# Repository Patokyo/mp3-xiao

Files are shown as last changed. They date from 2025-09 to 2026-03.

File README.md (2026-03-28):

# MP3 Xiao

A portable DIY MP3 player built using the Seeed Studio XIAO ESP32-S3

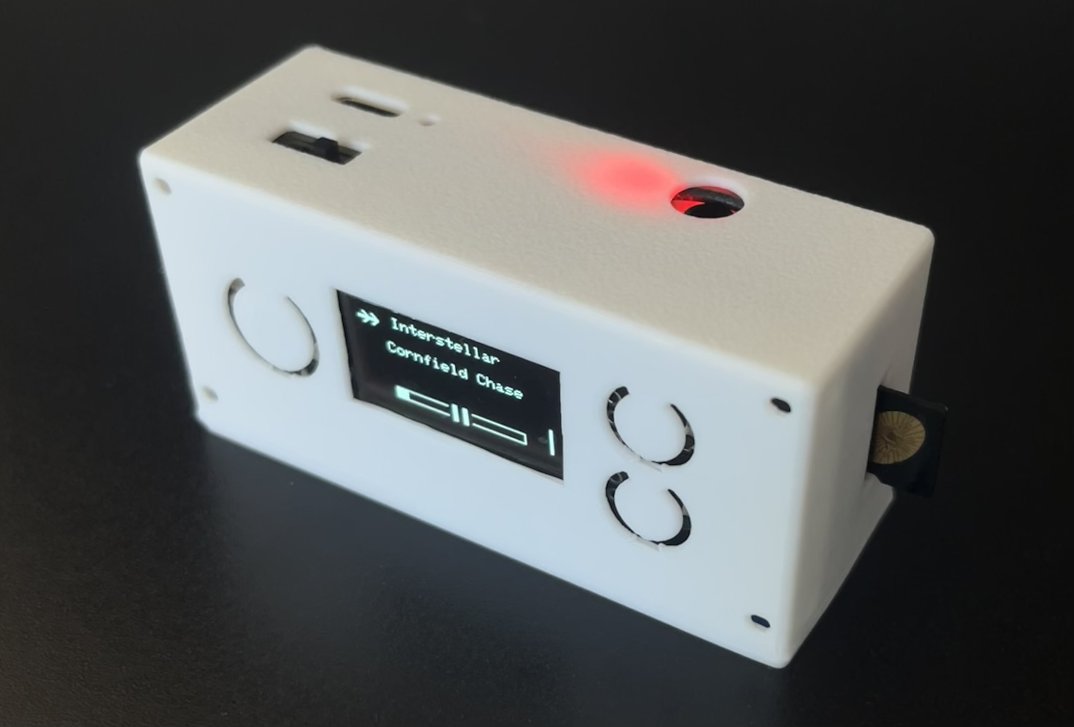
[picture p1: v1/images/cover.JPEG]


## Overview

MP3 Xiao is a compact, battery-powered music player designed from scratch. It features SD card audio playback, a simple button-based interface, and a clean OLED display for navigation and playback information.

## Hardware Components

| Component | Description | Image |
|---|---|---|
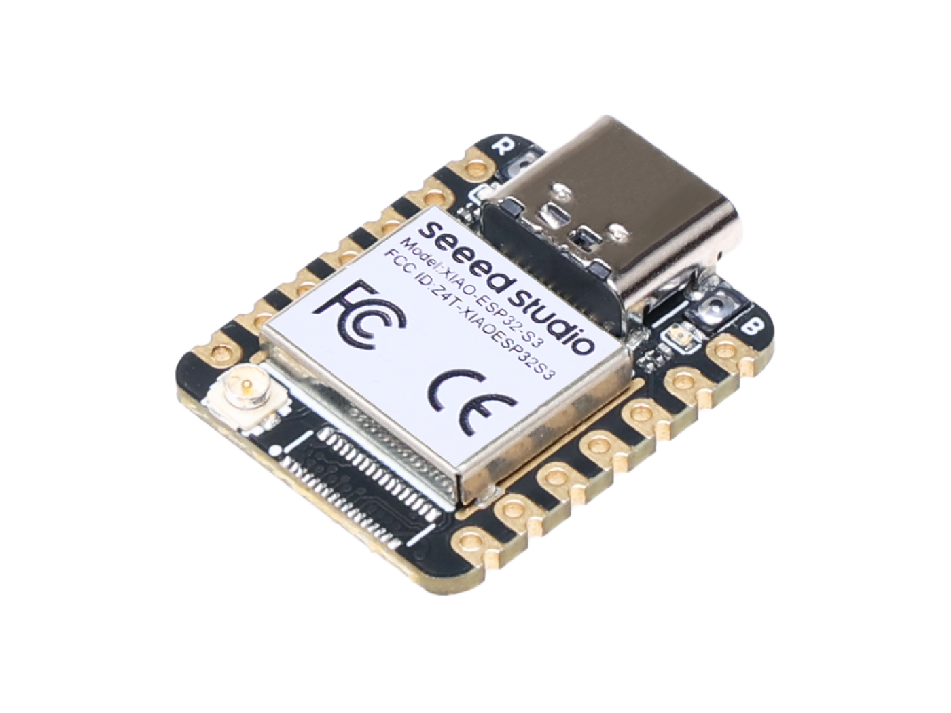
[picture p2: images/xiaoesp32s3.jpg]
| Microcontroller | Seeed Studio XIAO ESP32-S3 |  |
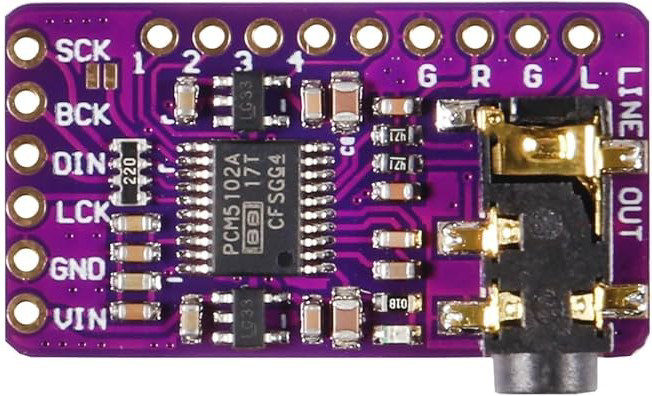
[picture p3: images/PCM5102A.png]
| DAC | PCM5102A (I2S, 3.5mm audio output) |  |
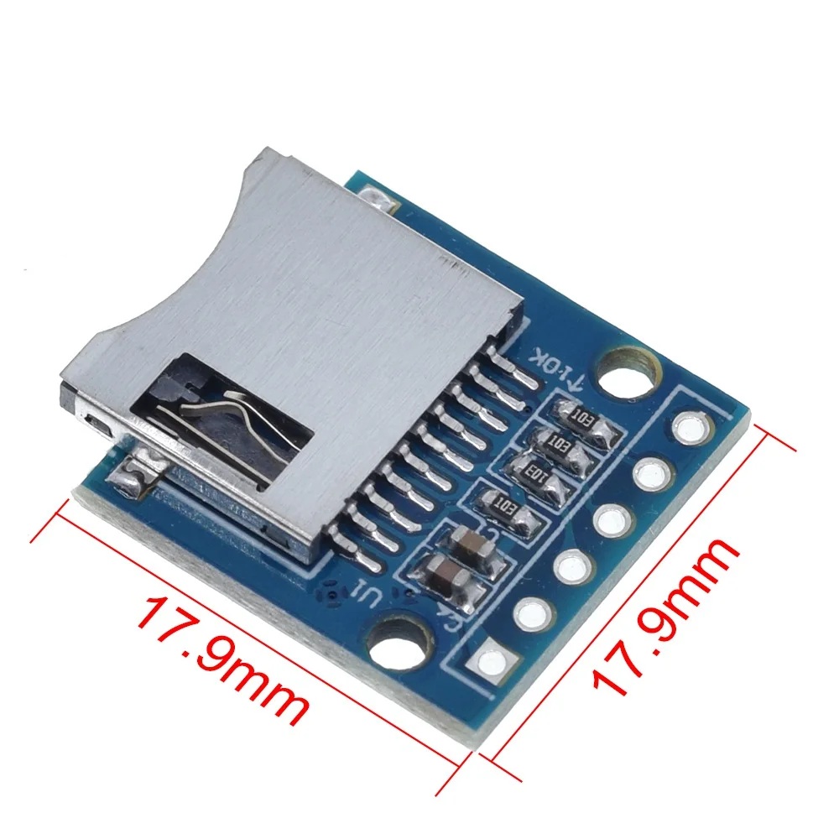
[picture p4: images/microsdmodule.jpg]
| Storage | MicroSD card module |  |
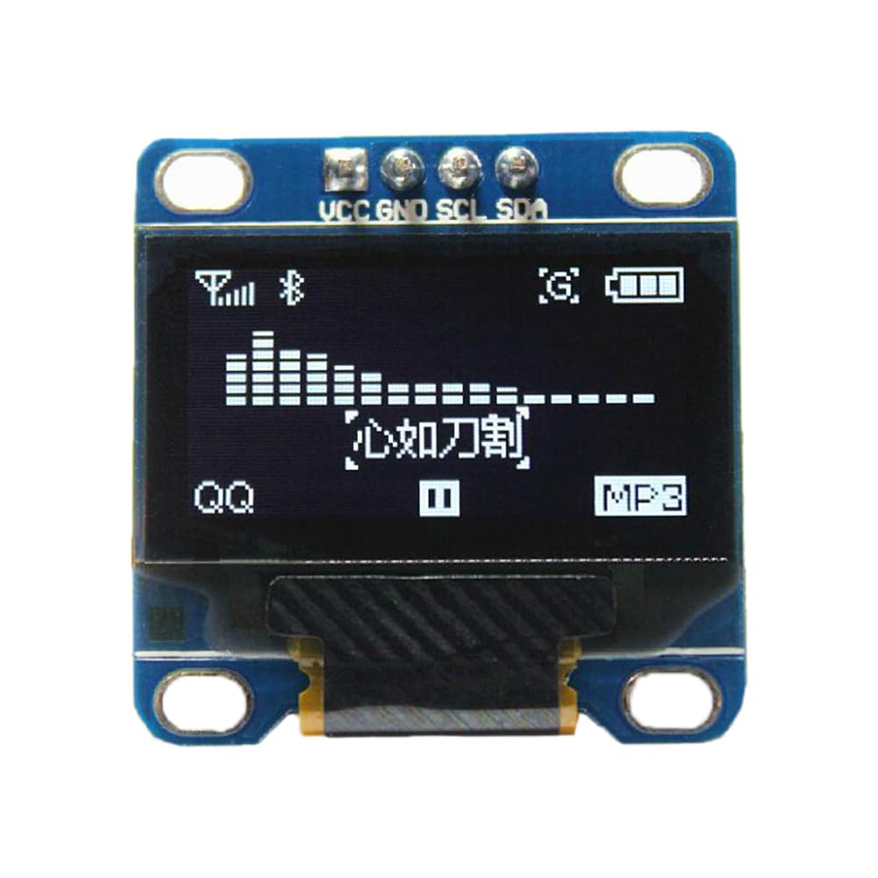
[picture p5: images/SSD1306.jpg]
| Display | SSD1306 OLED (128×64, I2C, 4-pin) |  |
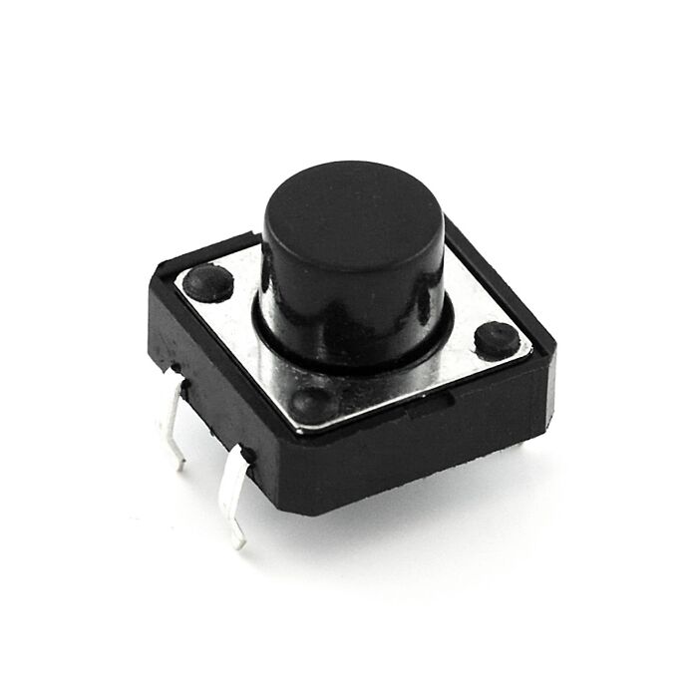
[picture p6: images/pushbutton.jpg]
| Input | 3× push buttons (via resistor ladder) |  |
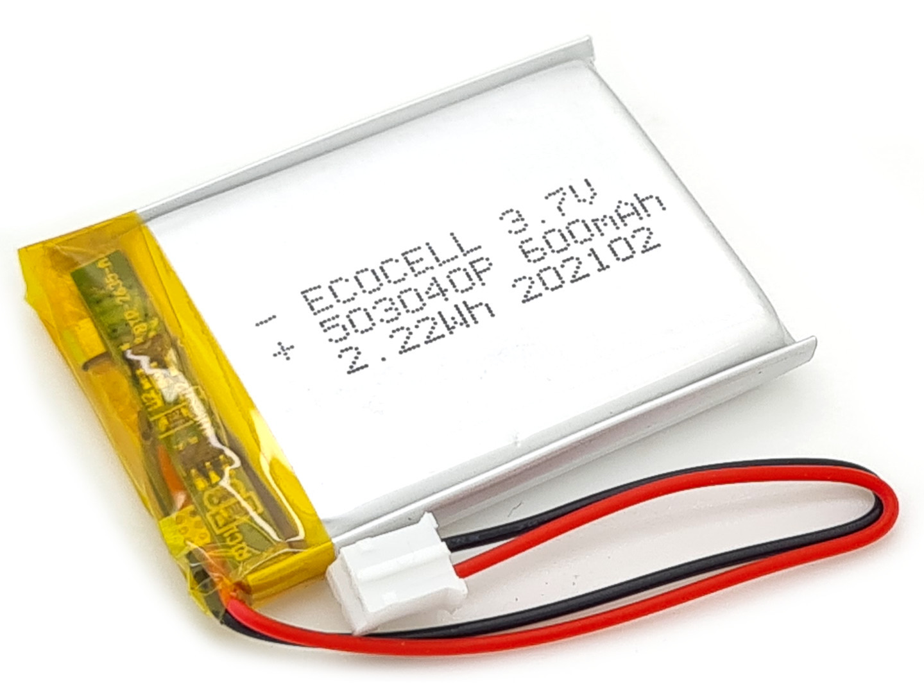
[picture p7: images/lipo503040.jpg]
| Power | LiPo battery with charging circuit (600mAh 3.7V 503040) |  |
## Features
🎵 MP3 playback from SD card

📁 Album & Playlist selection

🔀 Sequential and shuffle playback options

🔊 Volume control

🔋 Portable battery-powered design

🧵 3D-printed case

🤏 Small form factor

## About the device
I was looking for a small, simple, cheap and high quality mp3 player but couldn't find one that fit all my needs - so I built one! All the components together cost less than $40 AUD, it fits in my pocket and the audio playback is crisp. The files in this repo consist of all my prototyping and testing to get all the components to work together, my C++ Arduino firmware for the device (including a python script to format the sd card so the esp32 can understand) and the CAD files for my 3d-printed case design. I also included some photos of the finished v1 device.

## UI Showcase

### Initialising...
Shows the text "Initialising..." on the OLED whilst the device sets up the SD card and chooses the first song to play.

### Shuffle All
On startup the device defaults to shuffle all mode, which plays tracks randomly from anywhere on the sd card. Shows song and artist name, along with a progress and volume bar.

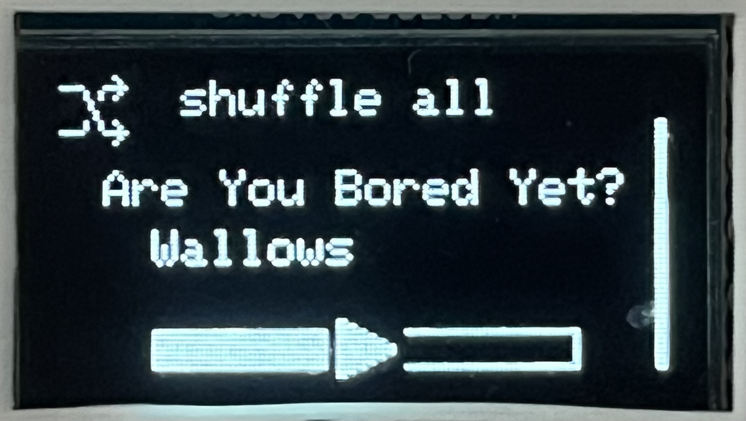
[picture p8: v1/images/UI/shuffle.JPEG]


### Navigation
Hold down the big button to enter navigation mode, using the up and down button to select between Shuffle, Albums and Playlists, then release to continue.

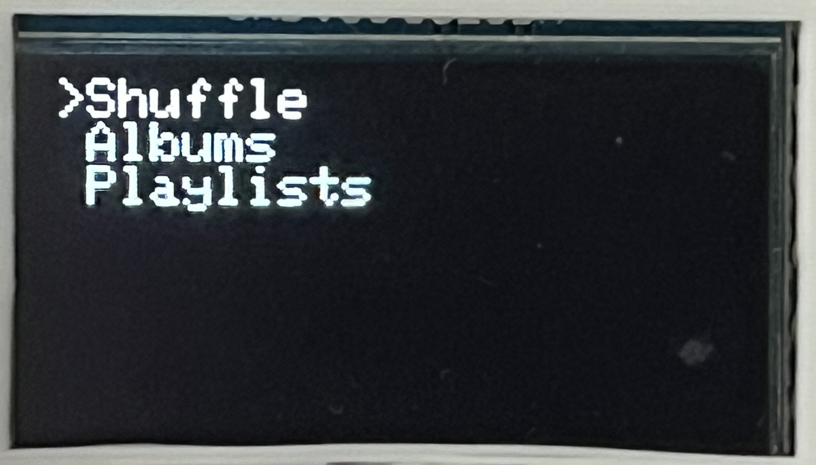
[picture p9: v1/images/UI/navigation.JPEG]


### Select
Displays all the albums or playlists stored on the SD card in alphabetical order. Use the up and down button to smoothly scroll through, and the big button to select.

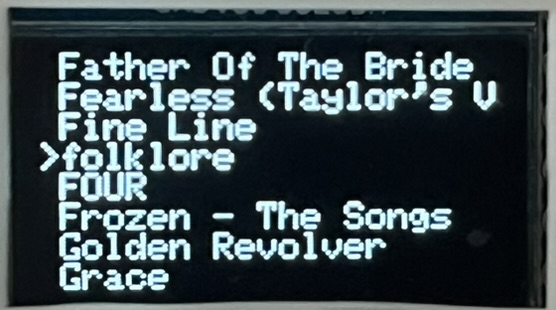
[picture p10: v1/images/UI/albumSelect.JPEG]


### Album Play
Displays the album name and a sequential indicator showing that it will play each song in album order. Shows song and artist name, along with a progress and volume bar.

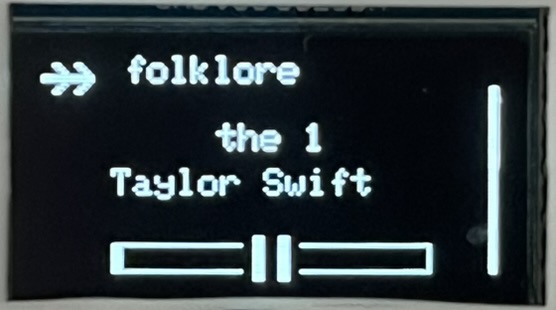
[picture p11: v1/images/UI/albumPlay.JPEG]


### Playlist Play
Displays the playlist name and a shuffle indicator showing that it will play songs in random order. Shows song and aritst name, along with a progress and volume bar.

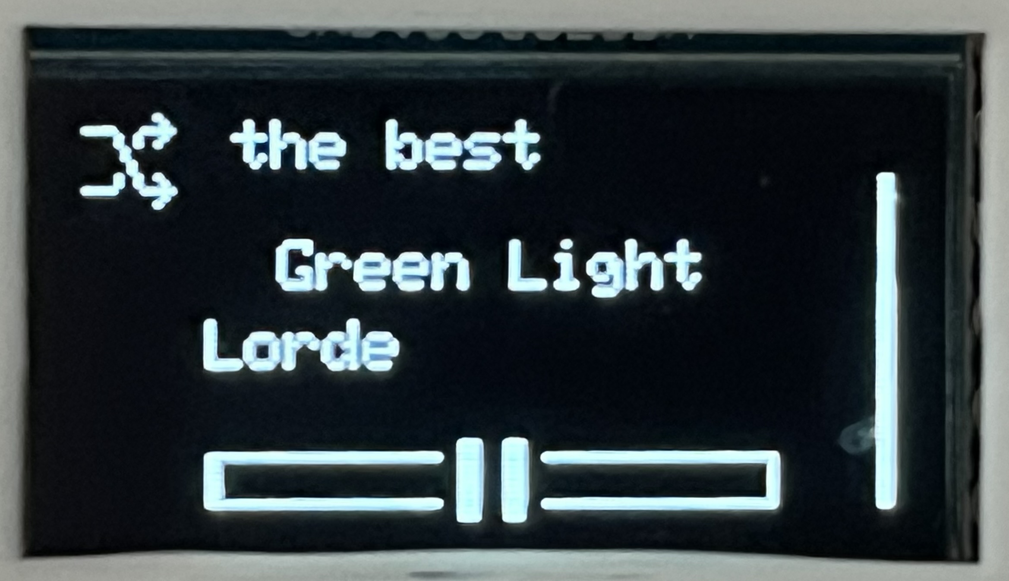
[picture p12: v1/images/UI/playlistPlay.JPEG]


## Updates
Currently working on V2 - a custom PCB to fit all the components into a nicer package.

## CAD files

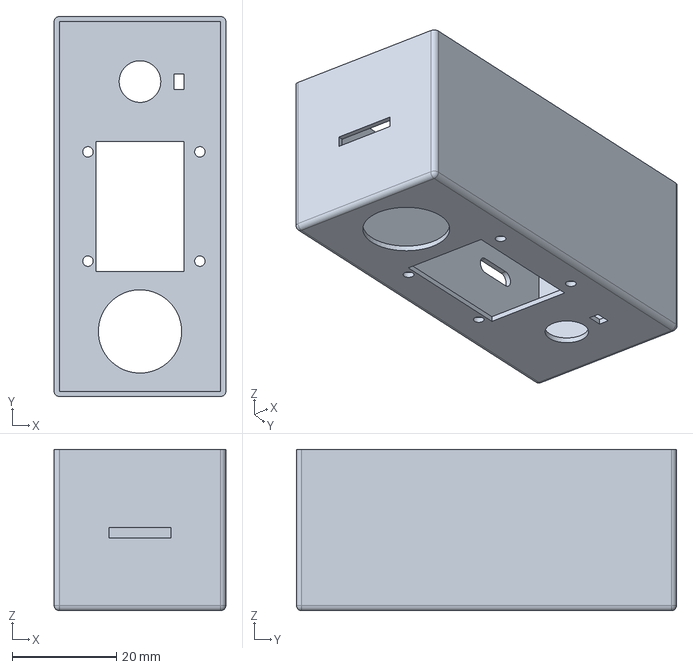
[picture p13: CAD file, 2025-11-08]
prototypes/SSD1306_freeCAD/mp3-xiao-SSD1306_V3.FCStd
33.0 x 73.0 x 31.0 mm

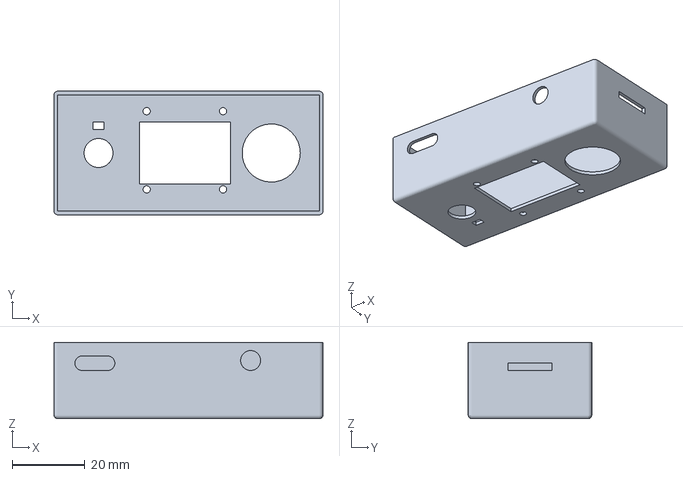
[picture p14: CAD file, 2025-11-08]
prototypes/SSD1306_freeCAD/mp3-xiao-SSD1306_V2.1.3mf
74.0 x 34.0 x 21.0 mm

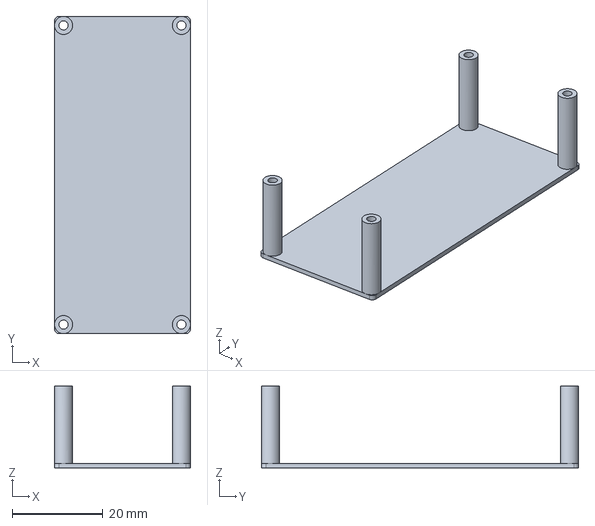
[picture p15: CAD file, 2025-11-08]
prototypes/SSD1306_freeCAD/mp3-xiao-SSD1306-BASE.FCStd
30.0 x 70.0 x 18.0 mm

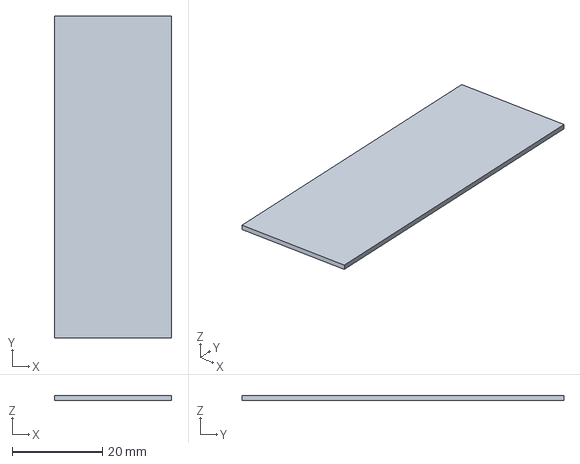
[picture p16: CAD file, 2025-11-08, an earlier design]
v1/case/mp3-xiao-case_roof.FCStd
26.0 x 71.5 x 1.00 mm

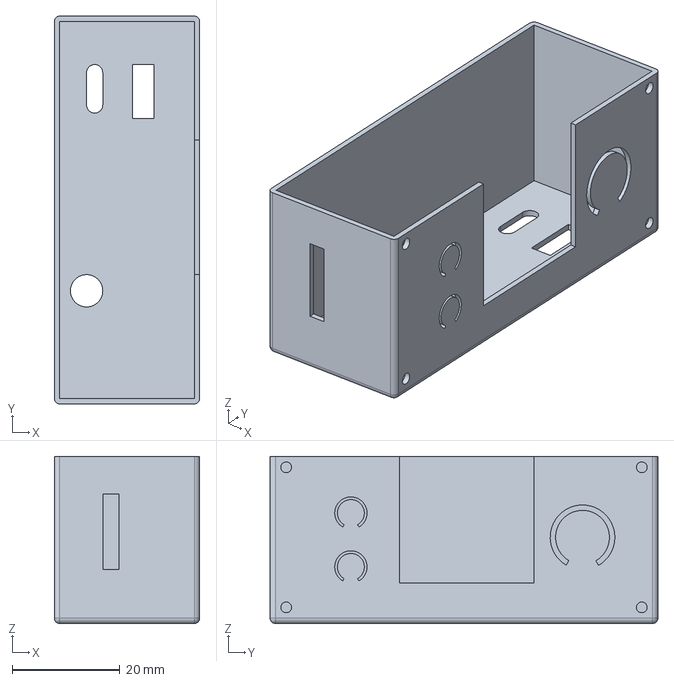
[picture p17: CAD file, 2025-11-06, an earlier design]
v1/case/mp3-xiao-FINAL/mp3-xiao-case.FCStd
27.0 x 72.0 x 31.0 mm

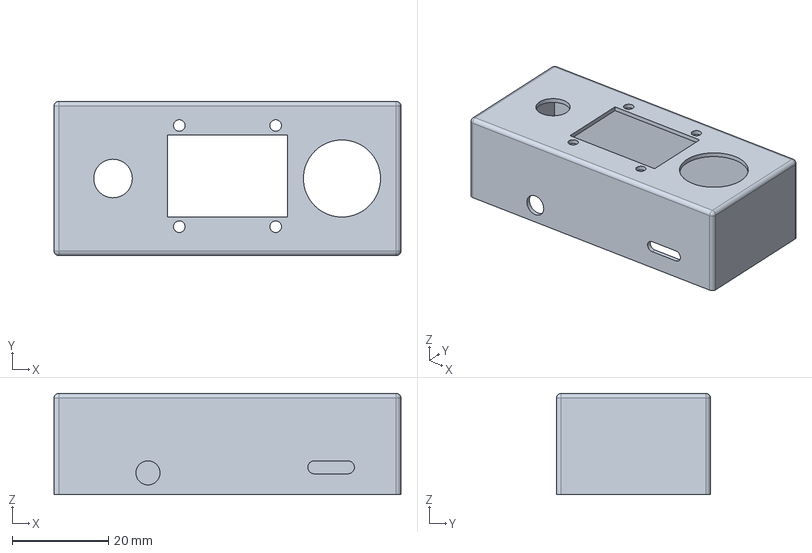
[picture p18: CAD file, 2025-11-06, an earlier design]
prototypes/mp3 xiao SSD1306/mp3-xiao-SSD1306_V1.FCStd
72.0 x 32.0 x 21.0 mm

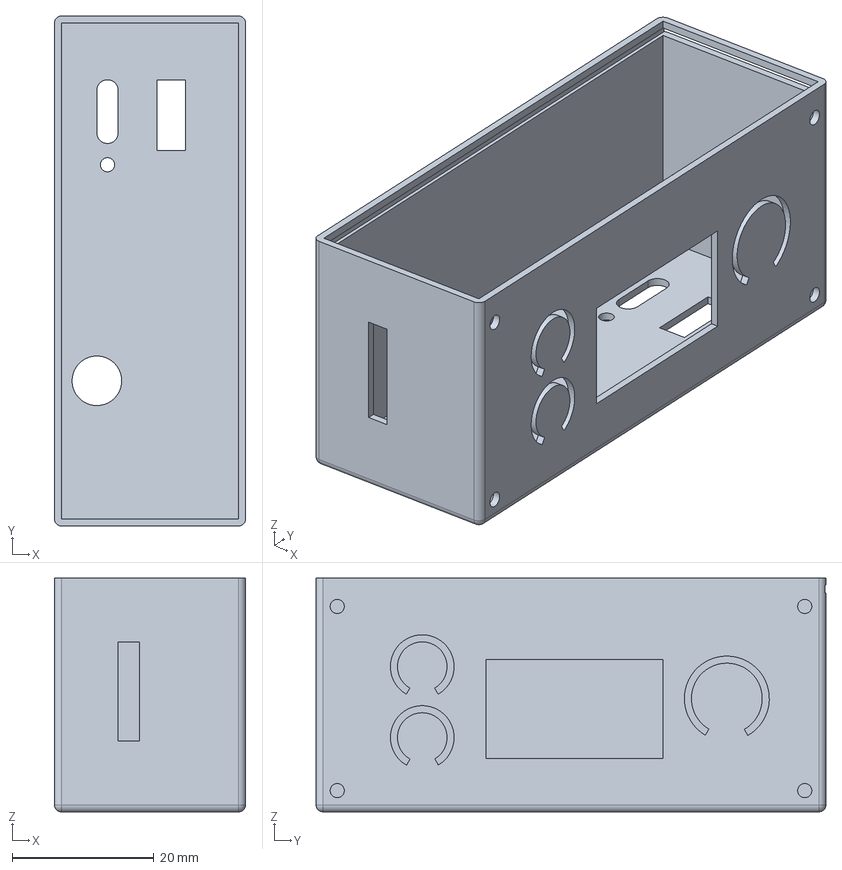
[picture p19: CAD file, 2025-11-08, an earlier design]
v1/case/mp3-xiao-case.FCStd
27.0 x 72.0 x 33.0 mm

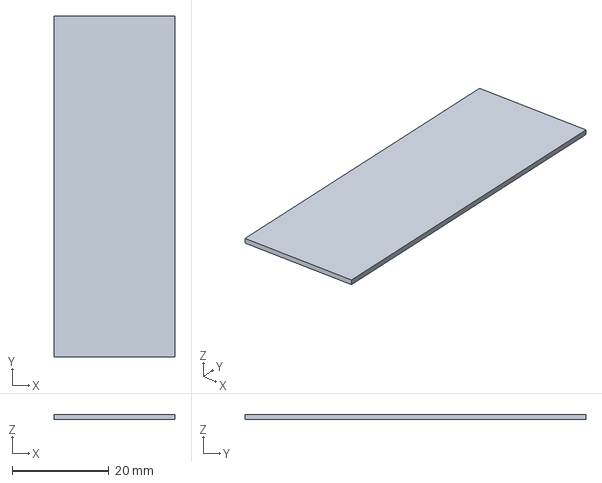
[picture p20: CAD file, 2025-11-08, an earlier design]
v1/case/mp3-xiao-roof.3mf
25.0 x 70.5 x 1.00 mm

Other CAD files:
prototypes/SSD1306_freeCAD/mp3-xiao-SSD1306_V3-Body.3mf
prototypes/mp3 xiao SSD1306/mp3-xiao-SSD1306_V2.FCStd
v1/case/mp3-xiao-case-Body.3mf
prototypes/SSD1306_freeCAD/mp3-xiao-SSD1306_V2.FCStd
prototypes/SSD1306_freeCAD/mp3-xiao-SSD1306_V1.FCStd
prototypes/SSD1306_freeCAD/mp3-xiao-SSD1306-BASE.3mf
prototypes/SSD1306_freeCAD/mp3-xiao-SSD1306_V2.3mf

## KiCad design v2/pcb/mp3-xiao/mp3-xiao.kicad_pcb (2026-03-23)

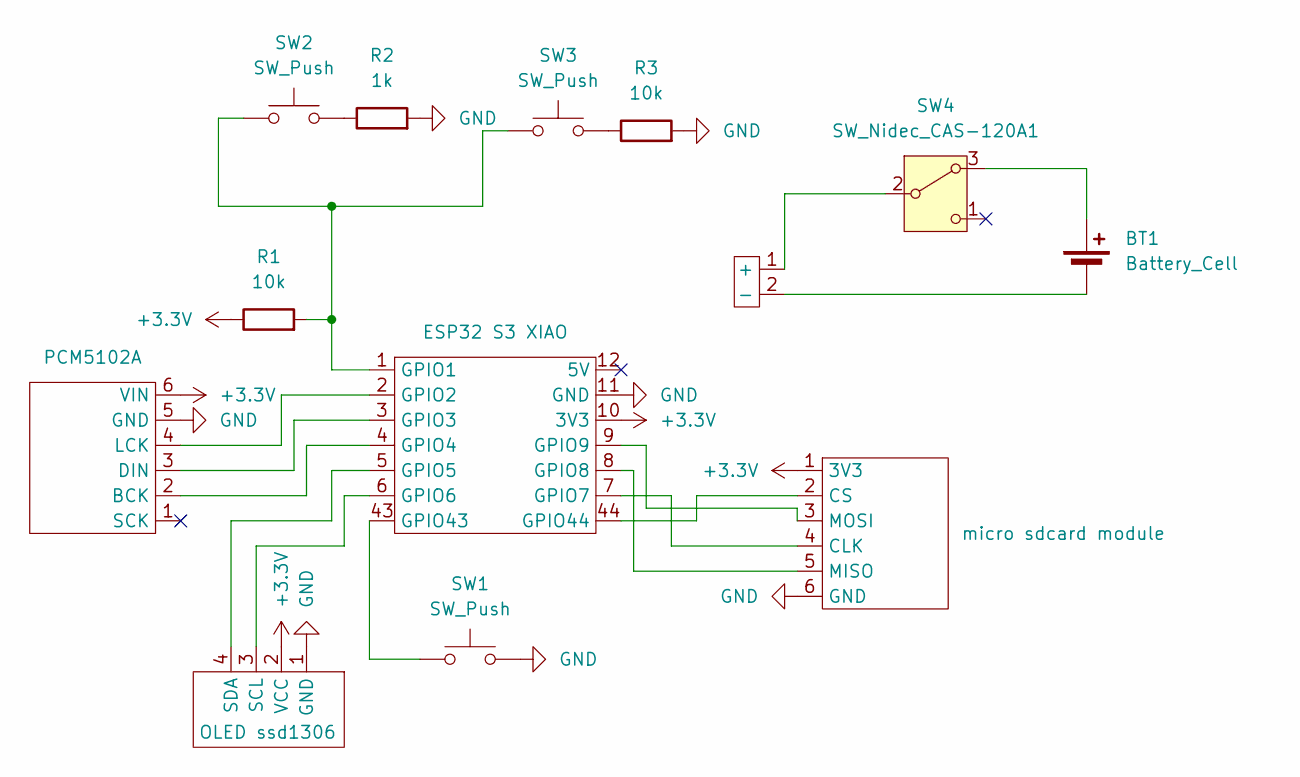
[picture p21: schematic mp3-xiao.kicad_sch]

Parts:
BT1: Battery_Cell
R1, R3: 10k; R_0805_2012Metric_Pad1.20x1.40mm_HandSolder
R2: 1k; R_0805_2012Metric_Pad1.20x1.40mm_HandSolder
SW1: SW_Push; SW_PUSH-12mm_Wuerth-430476085716
SW2, SW3: SW_Push; SW_PUSH_6mm
SW4: SW_Nidec_CAS-120A1; spdt slide switch
U1: OLED ssd1306
U2: ESP32 S3 XIAO
U3: micro sdcard module; micro sd card module
U4: PCM5102A
U5: battery_pads

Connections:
+3.3V: R1.1, U1.2 (VCC), U2.10 (3V3), U3.1 (3V3), U4.6 (VIN)
GND: R2.2, R3.2, SW1.2, U1.1 (GND), U2.11 (GND), U3.6 (GND), U4.5 (GND)
unnamed: BT1.1 (+), SW4.3 (A)
unnamed: BT1.2 (-), U5.2 (-)
unnamed: R2.1, SW2.2
unnamed: R3.1, SW3.2
unnamed: SW4.2 (B), U5.1 (+)
unnamed: U1.3 (SCL), U2.6 (GPIO6)
unnamed: U1.4 (SDA), U2.5 (GPIO5)
unnamed: R1.2, SW2.1, SW3.1, U2.1 (GPIO1)
unnamed: U2.2 (GPIO2), U4.4 (LCK)
unnamed: U2.3 (GPIO3), U4.3 (DIN)
unnamed: U2.4 (GPIO4), U4.2 (BCK)
unnamed: U2.7 (GPIO7), U3.4 (CLK)
unnamed: U2.8 (GPIO8), U3.5 (MISO)
unnamed: U2.9 (GPIO9), U3.3 (MOSI)
unnamed: SW1.1, U2.43 (GPIO43)
unnamed: U2.44 (GPIO44), U3.2 (CS)

Board: 2 copper layers, 12 parts (1 on the bottom side), 16 nets, no tracks yet.

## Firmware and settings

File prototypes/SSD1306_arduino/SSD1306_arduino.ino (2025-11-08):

#include "Arduino.h"
#include "Audio.h"
#include "SPI.h"
#include "SD.h"
#include "FS.h"
#include <Wire.h>
#include <Adafruit_GFX.h>
#include <Adafruit_SSD1306.h>


// OLED - SH1107 128x128 I2C
#define SCREEN_WIDTH 128
#define SCREEN_HEIGHT 64
#define OLED_RESET -1     // No reset pin
Adafruit_SSD1306 display(SCREEN_WIDTH, SCREEN_HEIGHT, &Wire, OLED_RESET);

// Digital I/O used
#define SD_CS 44
#define SPI_MOSI 9
#define SPI_MISO 8
#define SPI_SCK 7
#define I2S_DOUT 3
#define I2S_BCLK 4
#define I2S_LRC 2
#define POT_PIN 1
#define BUTTON_PIN 43

Audio audio;

//variables
String UIMode = "play";       //play or select
String playMode = "shuffle";  //shuffle, straight
String selectMode;            //album, playlist

bool paused = false;
bool songEnd = false;

File currentAlbum;
String shuffleDir = "/";
String shuffleNext;

int volume = 12;
int selectionIndex;
int potValue;

String currentSongPath;
String currentAlbumDir;

String displayArtist;
String displayTitle;
String displayAlbum;
long songLength;
unsigned long songStartTime = 0;  // when the song started
unsigned long timepassed = 0;     // elapsed time in ms

#define MAX_ALBUMS 128
#define NAME_LEN 128
char albumPaths[MAX_ALBUMS][NAME_LEN];
int albumCount = 0;

#define MAX_PLAYLISTS 128
char playlistPaths[MAX_ALBUMS][NAME_LEN];
int playlistCount = 0;


//bitmaps
// 'play', 16x16px
const unsigned char bitmap_play[] PROGMEM = {
  0xc0, 0x00, 0xf0, 0x00, 0xfc, 0x00, 0xff, 0x00, 0xff, 0xc0, 0xff, 0xf0, 0xff, 0xfc, 0xff, 0xff,
  0xff, 0xff, 0xff, 0xfc, 0xff, 0xf0, 0xff, 0xe0, 0xff, 0x80, 0xfe, 0x00, 0xf8, 0x00, 0xe0, 0x00
};

// 'pause', 16x16px
const unsigned char bitmap_pause[] PROGMEM = {
  0x00, 0x00, 0x00, 0x00, 0x1c, 0x38, 0x1c, 0x38, 0x1c, 0x38, 0x1c, 0x38, 0x1c, 0x38, 0x1c, 0x38,
  0x1c, 0x38, 0x1c, 0x38, 0x1c, 0x38, 0x1c, 0x38, 0x1c, 0x38, 0x1c, 0x38, 0x00, 0x00, 0x00, 0x00
};

// 'rewind', 16x16px
const unsigned char bitmap_rewind[] PROGMEM = {
  0x00, 0x00, 0x00, 0x00, 0x40, 0x0c, 0x40, 0x3c, 0x40, 0xfc, 0x43, 0xfc, 0x4f, 0xfc, 0x7f, 0xfc,
  0x7f, 0xfc, 0x4f, 0xfc, 0x43, 0xfc, 0x40, 0xfc, 0x40, 0x3c, 0x40, 0x0c, 0x00, 0x00, 0x00, 0x00
};

// 'skip', 16x16px
const unsigned char bitmap_skip[] PROGMEM = {
  0x00, 0x00, 0x00, 0x00, 0x60, 0x04, 0x78, 0x04, 0x7e, 0x04, 0x7f, 0x84, 0x7f, 0xe4, 0x7f, 0xfc,
  0x7f, 0xfc, 0x7f, 0xe4, 0x7f, 0x84, 0x7e, 0x04, 0x78, 0x04, 0x60, 0x04, 0x00, 0x00, 0x00, 0x00
};

//shuffle
const unsigned char bitmap_shuffle[] PROGMEM = {
	0x00, 0x00, 0x00, 0x08, 0x00, 0x04, 0x7c, 0x3e, 0x02, 0x44, 0x02, 0x48, 0x01, 0x00, 0x01, 0x00, 
	0x00, 0x80, 0x00, 0x80, 0x02, 0x48, 0x02, 0x44, 0x7c, 0x3e, 0x00, 0x04, 0x00, 0x08, 0x00, 0x00
};

// 'straight, 16x16px
const unsigned char bitmap_straight[] PROGMEM = {
	0x00, 0x00, 0x00, 0x00, 0x00, 0x00, 0x00, 0x00, 0x0c, 0x30, 0x06, 0x18, 0x03, 0x0c, 0x7f, 0xfe, 
	0x7f, 0xfe, 0x03, 0x0c, 0x06, 0x18, 0x0c, 0x30, 0x00, 0x00, 0x00, 0x00, 0x00, 0x00, 0x00, 0x00
};


void my_audio_info(Audio::msg_t m) {
  String type = String(m.s);
  String message = String(m.msg);

  if (type == "id3data") {
    int colonIndex = message.indexOf(':');
    if (colonIndex > 0) {
      String field = message.substring(0, colonIndex);
      String value = message.substring(colonIndex + 2);

      if (field == "Artist") {
        displayArtist = value;
      } else if (field == "Title") {
        displayTitle = value;
      } else if (field == "Album") {
        displayAlbum = value;
      } else if (field == "Length (ms)") {
        songLength = value.toInt();
      }
    }
  } else if (type == "eof") {
    songEnd = true;
  }
}


void setup() {
  Audio::audio_info_callback = my_audio_info;
  pinMode(SD_CS, OUTPUT);
  digitalWrite(SD_CS, HIGH);
  SPI.begin(SPI_SCK, SPI_MISO, SPI_MOSI);
  SPI.setFrequency(10000000);
  Serial.begin(115200);
  SD.begin(SD_CS);
  display.begin(SSD1306_SWITCHCAPVCC,0x3C);
  audio.setPinout(I2S_BCLK, I2S_LRC, I2S_DOUT);
  audio.setVolume(volume);
  pinMode(BUTTON_PIN, INPUT_PULLUP);

  display.clearDisplay();
  display.setTextSize(1);
  display.setTextColor(SSD1306_WHITE);
  display.println("Initialising...");
  display.display();

  shufflepick(shuffleDir);
  shuffle();
  cacheAlbums();
  cachePlaylists();
  Serial.print("Free ram heap: ");
  Serial.println(ESP.getFreeHeap());
}

void loop() {
  vTaskDelay(1);
  audio.loop();

  if (digitalRead(BUTTON_PIN) == LOW) {
    if (UIMode == "play") {
      paused = !paused;  // toggle pause/play
      audio.pauseResume();
      playUI();

      unsigned long pressStart = millis();
      bool doublePressed = false;
      while (digitalRead(BUTTON_PIN) == LOW) {
        if ((millis() - pressStart) > 1000) {
          int index;
          while (digitalRead(BUTTON_PIN) == LOW) {
            updatePot();
            index = map(potValue, 0, 4095, 0, 2);
            display.clearDisplay();
            display.setCursor(0, 0);
            if (index == 0) {
              display.print(">");
              display.println("Shuffle");
              display.println(" Albums");
              display.println(" Playlists");
            } else if (index == 1) {
              display.println(" Shuffle");
              display.print(">");
              display.println("Albums");
              display.println(" Playlists");
            } else if (index == 2) {
              display.println(" Shuffle");
              display.println(" Albums");
              display.print(">");
              display.println("Playlists");
            }
            display.display();
          }
          if (index == 0) {
            UIMode = "play";
            playMode = "shuffle";
            shuffleDir = "/";
            shuffle();
          } else if (index == 1) {
            UIMode = "select";
            selectMode = "album";
          } else if (index == 2) {
            UIMode = "select";
            selectMode = "playlist";
          }
          break;
        }
      }

      while (millis() - pressStart < 500) {
        if (digitalRead(BUTTON_PIN) == LOW) {
          doublePressed = true;
          // wait for release to avoid retriggering
          while (digitalRead(BUTTON_PIN) == LOW)
            ;
          break;
        }
      }

      if (doublePressed) {
        songEnd = true;  // double press action
        display.setCursor(0, 120);
        display.println("Skipped!");
        display.display();
        return;
      }
    }
  }

  if (UIMode == "play") {
    if (songEnd) {
      if (playMode == "shuffle") {
        shuffle();
      } else if (playMode == "straight") {
        nextSong();
      }
      songEnd = false;
    }
    updatePot();
    volume = map(potValue, 0, 4095, 0, 21);  // 0-21 matches your audio.setVolume();
    audio.setVolume(volume);
    playUI();
  } else if (UIMode == "select") {
    if(selectMode=="album"){
      updatePot();
      selectionIndex = map(potValue, 0, 4095, 0, albumCount - 1);
      if (digitalRead(BUTTON_PIN) == LOW) {
        playAlbum(String(albumPaths[selectionIndex]));
        playMode = "straight";
        UIMode = "play";
        delay(200);
      }
      selectUI();
    } else if(selectMode=="playlist"){
      updatePot();
      selectionIndex = map(potValue, 0, 4095, 0, playlistCount - 1);
      if (digitalRead(BUTTON_PIN) == LOW) {
        shuffleDir = "/" + String(playlistPaths[selectionIndex]);
        UIMode = "play";
        shufflepick(shuffleDir);
        shuffle();
        delay(200);
      }
      selectUI();
    }
    

  }

  if (!paused && !songEnd) {
    timepassed = millis() - songStartTime;
  }
}

int countLines(File file) {
  int lines = 0;
  while (file.available()) {
    if (file.read() == '\n') lines++;
  }
  file.seek(0);  // rewind to start
  return lines;
}

String pickRandomLine(File file, int totalLines) {
  int target = random(totalLines);  // 0 .. totalLines-1
  int currentLine = 0;
  String line = "";

  while (file.available()) {
    char c = file.read();
    if (c == '\n') {
      if (currentLine == target) {
        return line;
      }
      line = "";
      currentLine++;
    } else {
      line += c;
    }
  }
  return line;  // fallback for last line
}

void shufflepick(String directory) {
  playMode = "shuffle";
  Serial.println("Directory: "+directory);
  File indexFile = SD.open(directory + "/index.txt");
  int totalSongs = countLines(indexFile);
  String currentSongPath = pickRandomLine(indexFile, totalSongs);
  indexFile.close();
  shuffleNext = currentSongPath;
}

void shuffle() {
  audio.connecttoFS(SD, shuffleNext.c_str());
  if (paused) {
    paused = false;
  }
  songStartTime = millis();
  timepassed = 0;
  shufflepick(shuffleDir);
}

void playAlbum(String albumDir) {
  currentAlbumDir = albumDir;
  currentAlbum = SD.open("/" + albumDir);
  File currentFile = currentAlbum.openNextFile();
  currentSongPath = albumDir + "/" + currentFile.name();
  audio.connecttoFS(SD, currentSongPath.c_str());
  if (paused) {
    paused = false;
  }
  songStartTime = millis();
  timepassed = 0;
}

void nextSong() {
  File currentFile = currentAlbum.openNextFile();
  audio.connecttoFS(SD, (String(currentAlbumDir) + "/" + currentFile.name()).c_str());
  if (paused) {
    paused = false;
  }
  songStartTime = millis();
  timepassed = 0;
}

void updatePot() {
  int potReading = analogRead(POT_PIN);  // 0 - 4095 on ESP32

  if (potReading != potValue) {  // only update if changed
    potValue = potReading;
  }
}

void playUI() {
  display.clearDisplay();
  display.setTextSize(1);

  if(playMode=="shuffle"){
    display.drawBitmap(0, 0, bitmap_shuffle, 16, 16, SSD1306_WHITE);
    display.setCursor(24, 4);
    String displayPath = shuffleDir;
    if(displayPath.length()>1){
      displayPath.remove(0, 11);
      if(displayPath.length()>17){
        displayPath = displayPath.substring(0, 18);
        display.setCursor(20, 4);
      }
    } else{
      displayPath = "shuffle all";
      display.setCursor(26, 4);
    }
    display.print(displayPath);
  } else{
    display.drawBitmap(0, 0, bitmap_straight, 16, 16, SSD1306_WHITE);
    display.setCursor(24, 4);
    String albumName = currentAlbum.name();

    if (albumName.length() > 17) {
      albumName = albumName.substring(0, 18);
      display.setCursor(20, 4);
    }

    display.print(albumName);
  }

  // Center title
  int16_t x1, y1;
  uint16_t w, h;
  display.getTextBounds(displayTitle.c_str(), 0, 0, &x1, &y1, &w, &h);
  display.setCursor((SCREEN_WIDTH - w) / 2, 30);
  if(displayTitle.length()>19){
    displayTitle = displayTitle.substring(0, 19);
  }
  display.println(displayTitle);
  display.setTextSize(1);
  display.setCursor(20, 56);
  if(displayArtist.length()>14){
    displayArtist = displayArtist.substring(0, 15);
  }
  display.println(displayArtist);

  display.drawBitmap(20, 72, bitmap_rewind, 16, 16, SSD1306_WHITE);

  if (paused) {
    display.drawBitmap(56, 72, bitmap_play, 16, 16, SSD1306_WHITE);
  } else {
    display.drawBitmap(56, 72, bitmap_pause, 16, 16, SSD1306_WHITE);
  }

  display.drawBitmap(92, 72, bitmap_skip, 16, 16, SSD1306_WHITE);

  //progress bar
  display.drawRect(20, 92, 88, 15, SSD1306_WHITE);
  int progressWidth = map(timepassed, 0, songLength, 0, 88);  // 88 is bar width
  display.fillRect(20, 92, progressWidth, 15, SSD1306_WHITE);

  //volume bar
  int filledHeight = map(volume, 0, 21, 0, 100);
  display.drawRect(120, 20, 5, 100, SSD1306_WHITE);
  display.fillRect(120, 20 + (100 - filledHeight), 5, filledHeight, SSD1306_WHITE);


  display.display();
}

void cacheAlbums() {
  albumCount = 0;  // reset

  File file = SD.open("/albums.txt");

  while (file.available() && albumCount < MAX_ALBUMS) {
    String line = file.readStringUntil('\n');
    line.trim();  // remove \r or spaces

    if (line.length() > 0) {
      // Copy into albumPaths buffer
      strncpy(albumPaths[albumCount], line.c_str(), NAME_LEN - 1);
      albumPaths[albumCount][NAME_LEN - 1] = '\0';  // ensure null termination
      albumCount++;
    }
  }

  file.close();
}

void cachePlaylists() {
  playlistCount = 0;

  File file = SD.open("/playlists.txt");

  while(file.available() && playlistCount < MAX_PLAYLISTS){
    String line = file.readStringUntil('\n');
    line.trim();

    if(line.length()>0){
      strncpy(playlistPaths[playlistCount], line.c_str(), NAME_LEN - 1);
      playlistPaths[playlistCount][NAME_LEN - 1] = '\0';
      playlistCount++;
    }
  }

  file.close();
}


void selectUI() {
  int count;
  char (*paths)[NAME_LEN];  // pointer to array of NAME_LEN chars
  int remove;

  if (selectMode == "album") {
      count = albumCount;
      paths = albumPaths;
      remove = 7;
  } else if (selectMode == "playlist") {
      count = playlistCount;
      paths = playlistPaths;
      remove = 10;
  }

  display.clearDisplay();
  display.setTextSize(1);

  const int visibleRows = 16;  // how many rows can fit on screen
  const int centerRow = visibleRows / 2;

  // Figure out which album should be at the top
  int startIndex = selectionIndex - centerRow;
  if (startIndex < 0) startIndex = 0;
  if (startIndex > count - visibleRows) {
    startIndex = count - visibleRows;
  }
  if (startIndex < 0) startIndex = 0;  // in case albumCount < visibleRows

  // Draw the visible list
  for (int i = 0; i < visibleRows && (startIndex + i) < count; i++) {
    display.setCursor(0, i * 8);  // 8 px per row for text size 1
    if ((startIndex + i) == selectionIndex) {
      display.print(">");
    } else {
      display.print(" ");
    }
    String path = String(paths[startIndex + i]);
    path.remove(0, remove);
    // Truncate to 20 chars
    if (path.length() > 20) {
      path = path.substring(0, 20);
    }
    display.println(path);
  }

  display.display();
}

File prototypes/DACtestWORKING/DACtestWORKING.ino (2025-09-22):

#include "Arduino.h"
#include "Audio.h"
#include "SPI.h"
#include "SD.h"
#include "FS.h"

// Digital I/O used
#define SD_CS          43
#define SPI_MOSI      9
#define SPI_MISO      8
#define SPI_SCK       7
#define I2S_DOUT      2
#define I2S_BCLK      1
#define I2S_LRC       3

Audio audio;

void my_audio_info(Audio::msg_t m) {
    Serial.printf("%s: %s\n", m.s, m.msg);
}

void setup() {
    Audio::audio_info_callback = my_audio_info;
    pinMode(SD_CS, OUTPUT);
    digitalWrite(SD_CS, HIGH);
    SPI.begin(SPI_SCK, SPI_MISO, SPI_MOSI);
    SPI.setFrequency(1000000);
    Serial.begin(115200);
    SD.begin(SD_CS);
    audio.setPinout(I2S_BCLK, I2S_LRC, I2S_DOUT);
    audio.setVolume(12);
    audio.connecttoFS(SD, "07 Cherub.mp3");
}

void loop(){
    vTaskDelay(1);
    audio.loop();
}

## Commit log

2025-09-30 created 3d model of case
    [mp3-xiao-SSD1306_V1.FCStd, mp3-xiao-SSD1306_V2.FCStd]
2025-11-06 new case proto
    [mp3-xiao-SSD1306_V1.FCStd, mp3-xiao-SSD1306_V2.FCStd, mp3-xiao-case.FCStd]
2025-11-08 worked on case
    [mp3-xiao-SSD1306-BASE.3mf, mp3-xiao-SSD1306-BASE.FCStd, mp3-xiao-SSD1306_V1.FCStd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]
2026-03-22 cleaned up files
    [mp3-xiao-SSD1306-BASE.3mf, mp3-xiao-SSD1306-BASE.FCStd, mp3-xiao-SSD1306_V1.FCStd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]
2026-03-22 began creating v2 pcb
    [mp3-xiao.kicad_pcb, mp3-xiao.kicad_sch]
2026-03-22 reorganised files
    [mp3-xiao.kicad_pcb, mp3-xiao.kicad_sch]
2026-03-23 worked on v2 pcb
    [mp3-xiao.kicad_pcb, mp3-xiao.kicad_sch]
2026-11-11 Started custom pcb version
2026-11-11 Build the custom PCB schematic around the XIAO ESP32-S3
    Replace the ESP32-S3-WROOM-1 with the XIAO ESP32-S3 (SMD) using Seeed's
    vendor symbols and footprints, then add and wire the rest of the board:
    PJ-320D audio jack, LiPo battery, PCM5102A DAC, microSD socket, OLED
    header, power switch, button ladder and passives. Resistors and
    capacitors use 0805 hand-solder footprints, and the XIAO footprint now
    carries Seeed's official 3D model so the board renders and exports
    mechanically.
2026-11-11 messed with pcb proto
